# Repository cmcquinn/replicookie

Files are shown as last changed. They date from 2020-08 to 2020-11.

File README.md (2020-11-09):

# Replicookie





KiCad design files for Replicookie, a 3D Printer driver board based around the [Snickerdoodle](https://krtkl.com/snickerdoodle/) development board.

This project is open-source hardware, licensed under the CERN 1.2 license.

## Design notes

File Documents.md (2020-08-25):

# Supporting Documentation

## Snickerdoodle Development Board

<!-- <img src=https://krtkl.com/wp-content/uploads/2019/05/snickerdoodle-cj-down-1200x375.png> -->

| Document | Type |
| --- | --- |
| [Snickerdoodle Schematic](https://raw.githubusercontent.com/krtkl/open-source-schematics/master/snickerdoodle/snickerdoodle-schematic-r4p1.pdf) | Schematic |
| [Specifications](https://krtkl.com/resources/docs/#specs-snickerdoodle) | Specifications |
| [r4.1 Pinout](https://krtkl.com/uploads/pinout-r4.1.pdf) | Pinout |
| [Footprint](https://krtkl.com/uploads/footprint-snickerdoodle.pdf) | Footprint |

## Gigabit Ethernet PHY

<!-- <img src=https://www.microchip.com/_images/products/medium/041233a1fdc57dbe34369f35a1d2452f.png width=20%> -->

| Document                                                                                                                 |
| ------------------------------------------------------------------------------------------------------------------------ |
| [KSZ9031RNX Datasheet](http://ww1.microchip.com/downloads/en/DeviceDoc/00002117F.pdf)                                    |
| [Hardware Design Checklist](http://ww1.microchip.com/downloads/en/DeviceDoc/KSZ9031RNX-HW-Design-Checklist-00003391.pdf) |
| [Optimized Power Scheme](http://ww1.microchip.com/downloads/en/Appnotes/ANLAN206-UNG.pdf)                                |
| [Gigabit Ethernet Design Guide](http://ww1.microchip.com/downloads/en/Appnotes/00002054A.pdf)                            |

## MIC33050 Regulator

| Document                                                                                                                                                         |
| ---------------------------------------------------------------------------------------------------------------------------------------------------------------- |
| [MIC33050 Datasheet](http://ww1.microchip.com/downloads/en/DeviceDoc/MIC33050-4MHz-Internal-Inductor-PWM-Buck-Power-Module-with-HyperLight-Load-DS20006120A.pdf) |

## RJ45 Jack

<!-- <img src=https://media.digikey.com/Photos/Pulse%20Photos/JK0654219NL.jpg width=20%/> -->

| Document                                                                                        |
| ----------------------------------------------------------------------------------------------- |
| [JK Series Datasheet](https://media.digikey.com/pdf/Data%20Sheets/Pulse%20PDFs/JK%20Series.pdf) |

## USB ULPI Transceiver

| Document                                                                                                                            |
| ----------------------------------------------------------------------------------------------------------------------------------- |
| [USB334x Datasheet](http://ww1.microchip.com/downloads/en/DeviceDoc/USB334x-Data-Sheet-DS00002646A.pdf)                             |
| [USB Device Design Checklist](http://ww1.microchip.com/downloads/en/Appnotes/00001863B.pdf)                                         |
| [ULPI Design Guide](http://ww1.microchip.com/downloads/en/Appnotes/AN19.17-Application-Note-DS00002944A.pdf)                        |
| [USB334x USB Transceiver Layout Guidelines](http://ww1.microchip.com/downloads/en/Appnotes/AN22.3-Application-Note-DS00002971A.pdf) |
| [USB3343 Evaluation Board Schematic](http://ww1.microchip.com/downloads/en/DeviceDoc/SCH_USB3343-XTAL.pdf)                          |

## USB 2.0 Hi-Speed Hub Controller

| Document                                                                           |
| ---------------------------------------------------------------------------------- |
| [USB251x Datasheet](http://ww1.microchip.com/downloads/en/DeviceDoc/00001692C.pdf) |

## Dual High Speed USB to Multipurpose UART/FIFO

| Document                                                                                      |
| --------------------------------------------------------------------------------------------- |
| [FT4232H Datasheet](https://www.ftdichip.com/Support/Documents/DataSheets/ICs/DS_FT4232H.pdf) |

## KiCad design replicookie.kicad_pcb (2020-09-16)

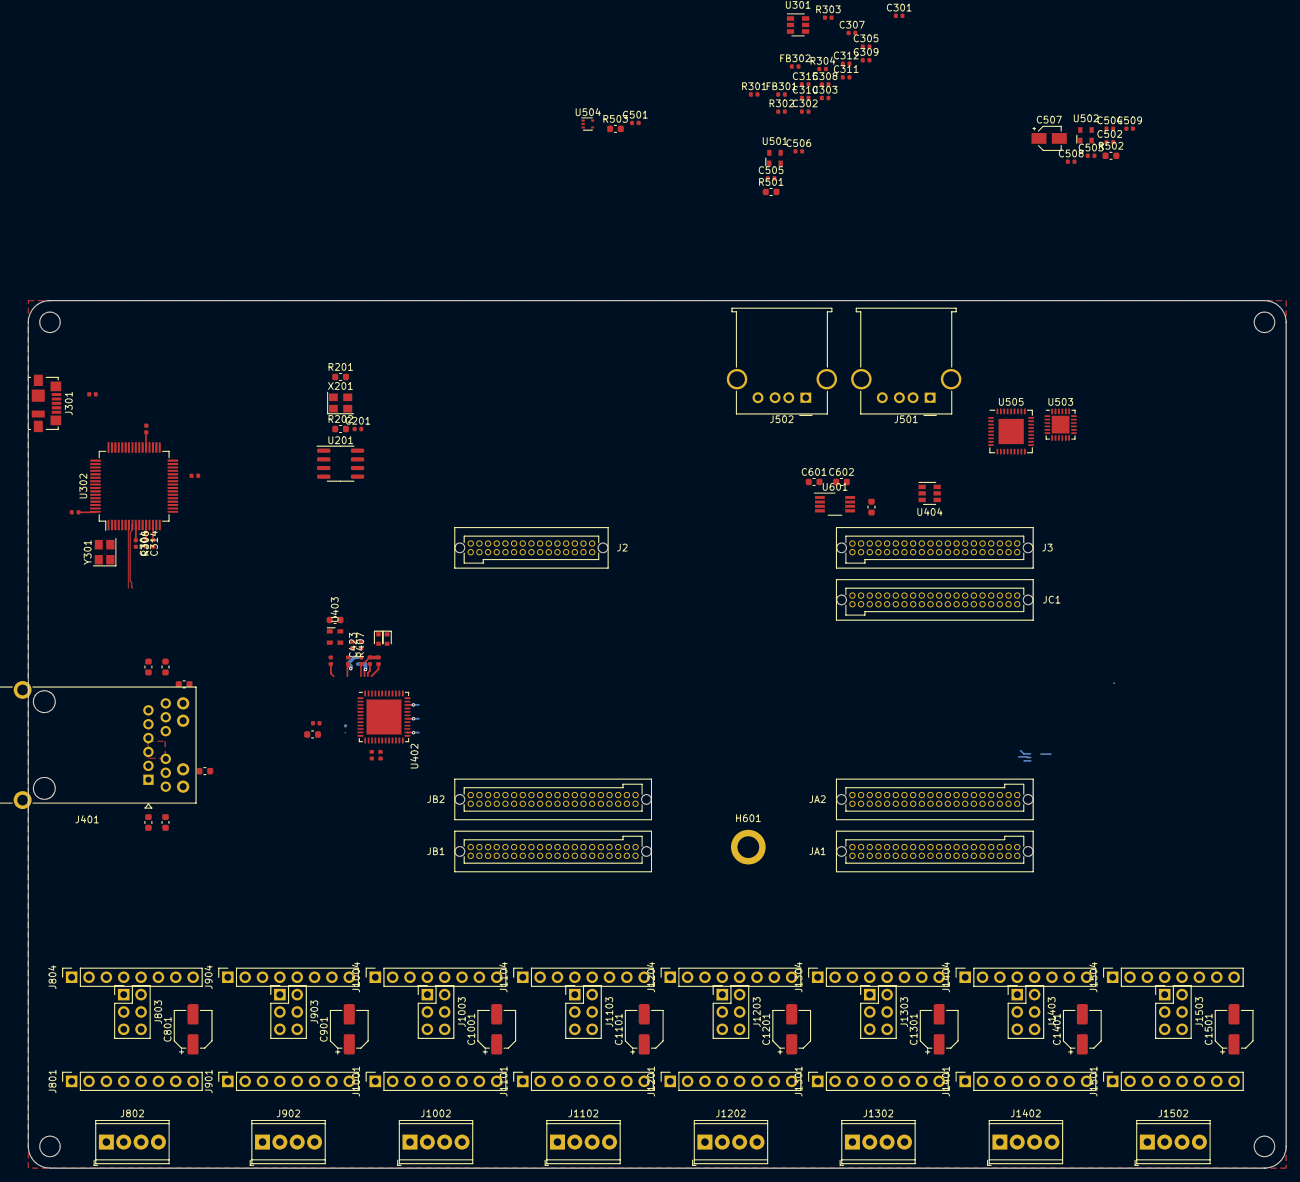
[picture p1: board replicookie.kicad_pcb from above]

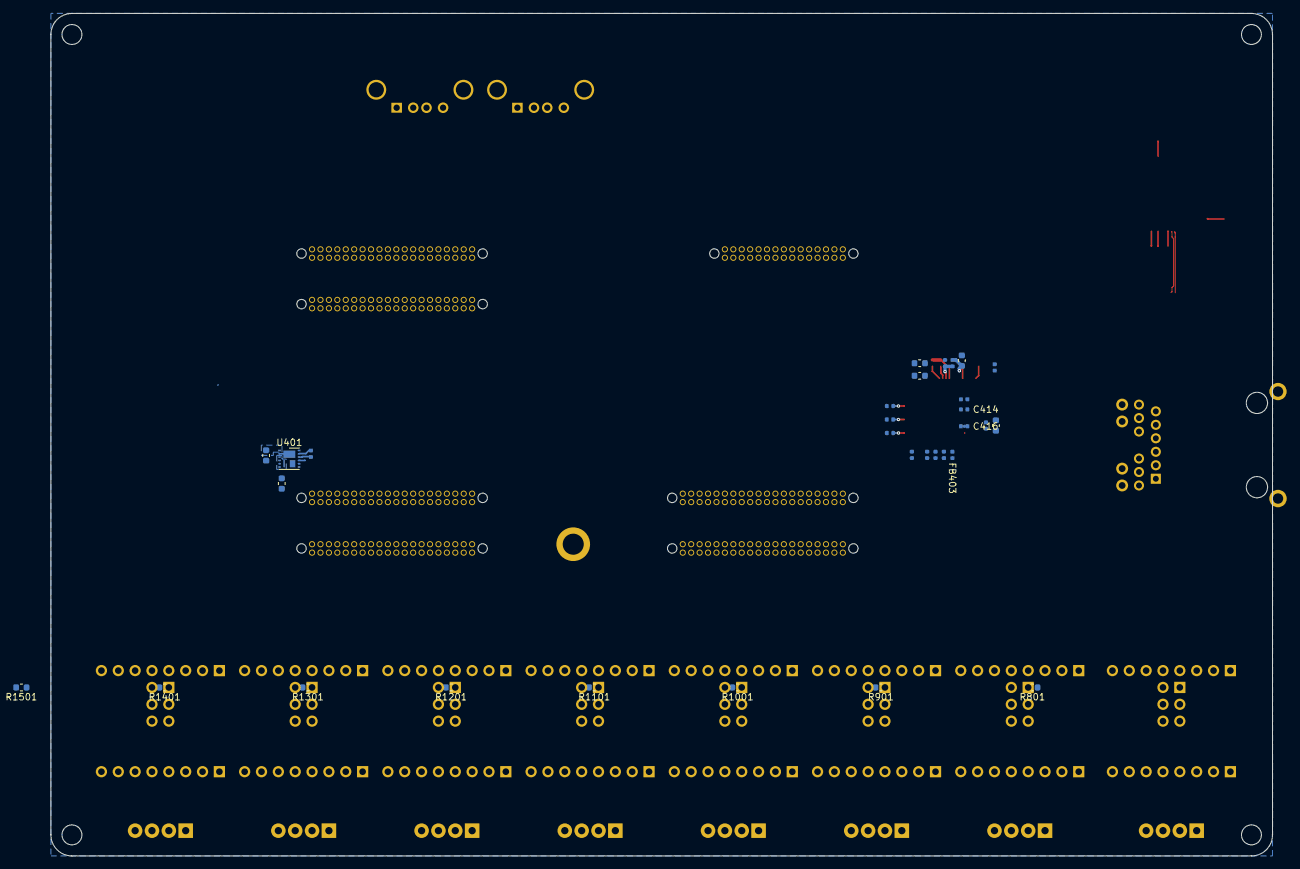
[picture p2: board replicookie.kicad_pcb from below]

Board: 4 copper layers, 184.1 x 127.0 mm, 163 parts (31 on the bottom side), 169 nets.

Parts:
C201, C501, C502: 0.01u; C_0402_1005Metric
C301, C303: 27p; C_0402_1005Metric
C302, C307, C308, C309, C310, C311, C312, C313, C314, C315, C408, C409, C410, C411, C412, C413, C414, C415, C416, C417, C418, C419, C420, C421, C504, C505, C508, C509: 0.1u; C_0402_1005Metric
C304, C305: 4.7u; C_0402_1005Metric
C306: 3.3u; C_0402_1005Metric
C401: 4.7u; C_0603_1608Metric
C402: 560p; C_0402_1005Metric
C403, C404, C405, C406, C407, C424: 10u; C_0603_1608Metric
C422: 0.01u; C_0603_1608Metric
C423: 10u; C_0402_1005Metric
C425, C426, C427, C428, C429, C601, C602: 0.1u; C_0603_1608Metric
C503, C506: 1u; C_0402_1005Metric
C507: 150u; CP_Elec_3x5.3
C801, C901, C1001, C1101, C1201, C1301, C1401, C1501: 100u 35V; CP_Elec_5x3
D401, D402: 1N4148WT; D_SOD-523
FB301, FB302: 80 ohm 100 MHz; L_0402_1005Metric
FB401, FB402, FB403: 100 ohms; L_0402_1005Metric
H101, H102, H103, H104: MountingHole; MountingHole_3mm
H601: MountingHole; Snickerdoodle_Mounting_Hole
J2: TFM-115-01-F-D-A; Samtec_TFM-115-01-F-D-A_2x15_P1.27mm_Horizontal
J3: TFM-120-01-F-D-A; Samtec_TFM-120-01-F-D-A_2x20_P1.27mm_Horizontal
J301: USB_B_Micro; USB_Micro-B_Molex_47346-0001
J401: JK0654219; RJ45_Pulse_JK0654219NL_Horizontal
J501, J502: USB_A; USB_A_Molex_67643_Horizontal
J801, J804, J901, J904, J1001, J1004, J1101, J1104, J1201, J1204, J1301, J1304, J1401, J1404, J1501, J1504: Conn_01x08_Female; PinSocket_1x08_P2.54mm_Vertical
J802, J902, J1002, J1102, J1202, J1302, J1402, J1502: Screw_Terminal_01x04; TerminalBlock_Phoenix_MPT-0,5-4-2.54_1x04_P2.54mm_Horizontal
J803, J903, J1003, J1103, J1203, J1303, J1403, J1503: Conn_02x03_Odd_Even; PinHeader_2x03_P2.54mm_Vertical
JA1, JA2: TFM-120-01-F-D-A; Samtec_TFM-120-01-F-D-A_2x20_P1.27mm_Horizontal
JB1, JB2: TFM-120-01-F-D-A; Samtec_TFM-120-01-F-D-A_2x20_P1.27mm_Horizontal
JC1: TFM-120-01-F-D-A; Samtec_TFM-120-01-F-D-A_2x20_P1.27mm_Horizontal
R201, R202: 2k; R_0603_1608Metric
R301, R302, R304, R401, R407: 10k; R_0402_1005Metric
R303: 2k; R_0402_1005Metric
R305: 12k; R_0402_1005Metric
R306, R403, R405: 1k; R_0402_1005Metric
R307: 470; R_0402_1005Metric
R402: 4.7k; R_0402_1005Metric
R404: 1.5k; R_0402_1005Metric
R406: 12.1k; R_0402_1005Metric
R408, R409: 75; R_0603_1608Metric
R501: 8.06k 1%; R_0603_1608Metric
R502: 10k 1/16W; R_0603_1608Metric
R503: 12k; R_0603_1608Metric
R801, R901, R1001, R1101, R1201, R1301, R1401, R1501: 10k; R_0603_1608Metric
U201: DS1307ZN+; SOIC-8_3.9x4.9mm_P1.27mm
U301: 93LCxxBxxOT; SOT-23-6
U302: FT4232H; LQFP-64_10x10mm_P0.5mm
U401: MIC33050-4YHL; HDFN-12-1EP_3x3mm_P0.5mm_EP1.8x1.125mm
U402: KSZ9031RNXCA; QFN-48-1EP_7x7mm_P0.5mm_EP5.15x5.15mm
U403: ASDMB-25.000MHz; Oscillator_SMD_Abracon_ASDMB-4Pin_2.5x2.0mm
U404: 74LVC2G07; SOT-23-6
U501: ASDMB-24.000MHz-C; Oscillator_SMD_Abracon_ASDMB-4Pin_2.5x2.0mm
U502: ASDMB-26.000MHz-C; Oscillator_SMD_Abracon_ASDMB-4Pin_2.5x2.0mm
U503: USB3343; QFN-24-1EP_4x4mm_P0.5mm_EP2.6x2.6mm
U504: 74LVC1G07; SOT-553
U505: USB2514B_Bi; QFN-36-1EP_6x6mm_P0.5mm_EP3.7x3.7mm
U601: TCA9800; VSSOP-8_3.0x3.0mm_P0.65mm
X201: ASE-xxxMHz; Oscillator_SMD_Abracon_ASE-4Pin_3.2x2.5mm
Y301: ABM8-12.000MHZ-20; Crystal_SMD_Abracon_ABM8G-4Pin_3.2x2.5mm

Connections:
+1V8: C501.1, C502.1, C601.2, U501.1 (Standby), U501.4 (VDD), U502.1 (Standby), U502.4 (VDD), U504.5 (VCC), U601.1 (VCCA)
+3V3: C201.1, C309.1, C310.1, C311.1, C312.1, C401.1, C405.1, C408.1, C409.1, C410.1, C422.1, C429.1, C602.2, D401.1 (K), FB301.2, FB302.2, FB403.1, J801.2, J803.1, J803.2, J901.2, J903.1, J903.2, J1001.2, J1003.1, J1003.2, J1101.2, J1103.1, J1103.2, J1201.2, J1203.1, J1203.2, J1301.2, J1303.1, J1303.2, J1401.2, J1403.1, J1403.2, J1501.2, J1503.1, J1503.2, R201.1, R202.1, R301.1, R302.1, R304.1, R306.1, R401.1, R402.1, R404.1, R407.1, R408.2, R409.2, R801.1, R901.1, R1001.1, R1101.1, R1201.1, R1301.1, R1401.1, R1501.1, U201.8 (VCC), U302.20 (VCCIO), U302.31 (VCCIO), U302.42 (VCCIO), U302.50 (VREGIN), U302.56 (VCCIO), U401.1 (VIN), U401.9 (EN), U402.16 (DVDDH), U402.34 (DVDDH), U402.40 (DVDDH), U403.1 (Standby), U403.4 (VDD), U404.5 (VCC), U505.27 (VBUS_DET), U601.8 (VCCB), X201.1 (EN), X201.4 (Vdd)
+24V: C801.1, C901.1, C1001.1, C1101.1, C1201.1, C1301.1, C1401.1, C1501.1, J801.8, J901.8, J1001.8, J1101.8, J1201.8, J1301.8, J1401.8, J1501.8
/DRV0_CTRL.~EN: J804.8, R801.2
/DRV1_CTRL.~EN: J904.8, R901.2
/DRV2_CTRL.~EN: J1004.8, R1001.2
/DRV3_CTRL.~EN: J1104.8, R1101.2
/DRV4_CTRL.~EN: J1204.8, R1201.2
/DRV5_CTRL.~EN: J1304.8, R1301.2
/DRV6_CTRL.~EN: J1404.8, R1401.2
/DRV7_CTRL.~EN: J1504.8, R1501.2
/ETHERNET.MDC: JB2.37, U402.36 (MDC)
/ETHERNET.MDIO: JB2.35, R404.2, U402.37 (MDIO)
/ETHERNET.RXD0: JB2.30, U402.32 (RXD0/MODE0)
/ETHERNET.RXD1: JB2.26, U402.31 (RXD1/MODE1)
/ETHERNET.RXD2: JB2.24, U402.28 (RXD2/MODE2)
/ETHERNET.RXD3: JB2.20, U402.27 (RXD3/MODE3)
/ETHERNET.RX_CLK: JB2.36, U402.35 (RX_CLK/PHYAD2)
/ETHERNET.RX_CTL: JB2.32, U402.33 (RX_DV/CLK125_EN)
/ETHERNET.TXD0: JB2.4, U402.19 (TXD0)
/ETHERNET.TXD1: JB2.6, U402.20 (TXD1)
/ETHERNET.TXD2: JB2.8, U402.21 (TXD2)
/ETHERNET.TXD3: JB2.12, U402.22 (TXD3)
/ETHERNET.TX_CLK: JB2.14, U402.24 (GTX_CLK)
/ETHERNET.TX_CTL: JB2.18, U402.25 (TX_EN)
/Ethernet/25MHZ_CLK: U402.46 (XI), U403.3 (Out)
/Ethernet/AVDDH: C411.1, C412.1, C424.1, FB403.2, U402.1 (AVDDH), U402.12 (AVDDH)
/Ethernet/AVDDL: C406.1, C414.1, C416.1, FB401.1, U402.4 (AVDDL), U402.9 (AVDDL)
/Ethernet/AVDDL_PLL: C407.1, C417.1, FB402.1, U402.44 (AVDDL_PLL)
/Ethernet/CFF: C402.2, U401.11 (CFF)
/Ethernet/CT1: C428.1, J401.12 (MXCT1)
/Ethernet/CT2: C427.1, J401.6 (MXCT2)
/Ethernet/CT3: C426.1, J401.1 (MXCT3)
/Ethernet/CT4: C425.1, J401.7 (MXCT4)
/Ethernet/DVDDL: C402.1, C403.1, C404.1, C413.1, C415.1, C418.1, C419.1, C420.1, C421.1, FB401.2, FB402.2, U401.7 (VOUT), U401.8 (VOUT), U401.10 (SNS), U402.14 (DVDDL), U402.18 (DVDDL), U402.23 (DVDDL), U402.26 (DVDDL), U402.30 (DVDDL), U402.39 (DVDDL)
/Ethernet/ISET: R406.1, U402.48 (ISET)
/Ethernet/LED1: R403.1, U402.17 (LED1/PHAD0/PME_N1), U404.1
/Ethernet/LED1A: J401.16 (LED1+), R409.1
/Ethernet/LED1K: J401.15 (LED1-), U404.6
/Ethernet/LED2: R405.1, U402.15 (LED2/PHYAD1), U404.3
/Ethernet/LED2A: J401.14 (LED2+), R408.1
/Ethernet/LED2K: J401.13 (LED2-), U404.4
/Ethernet/LED_MODE: R401.2, U402.41 (CLK125_NDO/LED_MODE)
/Ethernet/TXRXA+: J401.11 (MX1+), U402.2 (TXRXP_A)
/Ethernet/TXRXA-: J401.10 (MX1-), U402.3 (TXRXM_A)
/Ethernet/TXRXB+: J401.4 (MX2+), U402.5 (TXRXP_B)
/Ethernet/TXRXB-: J401.5 (MX2-), U402.6 (TXRXM_B)
/Ethernet/TXRXC+: J401.3 (MX3+), U402.7 (TXRXP_C)
/Ethernet/TXRXC-: J401.2 (MX3-), U402.8 (TXRXM_C)
/Ethernet/TXRXD+: J401.8 (MX4+), U402.10 (TXRXP_D)
/Ethernet/TXRXD-: J401.9 (MX4-), U402.11 (TXRXM_D)
/Ethernet/~ENET_RST: C423.1, D401.2 (A), D402.2 (A), R407.2, U402.42 (RESET_N)
/Ethernet/~INT~/~PME2: R402.2, U402.38 (INT_N/PME_N2)
/FTDI/D+: J301.3 (D+), U302.8 (DP)
/FTDI/D-: J301.2 (D-), U302.7 (DM)
/FTDI/EECLK: R301.2, U301.4 (CLK), U302.62 (EECLK)
/FTDI/EECS: R304.2, U301.5 (CS), U302.63 (EECS)
/FTDI/EEDATA: R303.1, U301.3 (DI), U302.61 (EEDATA)
/FTDI/EEDO: R302.2, R303.2, U301.1 (DO)
/FTDI/FTDI_1V8: C306.1, C313.1, C314.1, C315.1, U302.12 (VCORE), U302.37 (VCORE), U302.49 (VREGOUT), U302.64 (VCORE)
/FTDI/OSCI: C301.2, U302.2 (OSCI), Y301.3
/FTDI/OSCO: C303.1, U302.3 (OSCO), Y301.1
/FTDI/REF: R305.1, U302.6 (REF)
/FTDI/VPHY: C305.1, C308.1, FB302.1, U302.4 (VPHY)
/FTDI/VPLL: C304.1, C307.1, FB301.1, U302.9 (VPLL)
/FTDI/~FTDI_RESET: R306.2, U302.14 (~RESET)
/MCU_~RST: J2.17, U302.29 (BDBUS3)
/MotorDrivers/Driver0/ADDR0: J803.4, J804.7
/MotorDrivers/Driver0/ADDR1: J803.3, J804.6
/MotorDrivers/Driver0/M1A: J801.4, J802.2
/MotorDrivers/Driver0/M1B: J801.3, J802.1
/MotorDrivers/Driver0/M2A: J801.5, J802.3
/MotorDrivers/Driver0/M2B: J801.6, J802.4
/MotorDrivers/Driver1/ADDR0: J903.4, J904.7
/MotorDrivers/Driver1/ADDR1: J903.3, J904.6
/MotorDrivers/Driver1/M1A: J901.4, J902.2
/MotorDrivers/Driver1/M1B: J901.3, J902.1
/MotorDrivers/Driver1/M2A: J901.5, J902.3
/MotorDrivers/Driver1/M2B: J901.6, J902.4
/MotorDrivers/Driver2/ADDR0: J1003.4, J1004.7
/MotorDrivers/Driver2/ADDR1: J1003.3, J1004.6
/MotorDrivers/Driver2/M1A: J1001.4, J1002.2
/MotorDrivers/Driver2/M1B: J1001.3, J1002.1
/MotorDrivers/Driver2/M2A: J1001.5, J1002.3
/MotorDrivers/Driver2/M2B: J1001.6, J1002.4
/MotorDrivers/Driver3/ADDR0: J1103.4, J1104.7
/MotorDrivers/Driver3/ADDR1: J1103.3, J1104.6
/MotorDrivers/Driver3/M1A: J1101.4, J1102.2
/MotorDrivers/Driver3/M1B: J1101.3, J1102.1
/MotorDrivers/Driver3/M2A: J1101.5, J1102.3
/MotorDrivers/Driver3/M2B: J1101.6, J1102.4
/MotorDrivers/Driver4/ADDR0: J1203.4, J1204.7
/MotorDrivers/Driver4/ADDR1: J1203.3, J1204.6
/MotorDrivers/Driver4/M1A: J1201.4, J1202.2
/MotorDrivers/Driver4/M1B: J1201.3, J1202.1
/MotorDrivers/Driver4/M2A: J1201.5, J1202.3
/MotorDrivers/Driver4/M2B: J1201.6, J1202.4
/MotorDrivers/Driver5/ADDR0: J1303.4, J1304.7
/MotorDrivers/Driver5/ADDR1: J1303.3, J1304.6
/MotorDrivers/Driver5/M1A: J1301.4, J1302.2
/MotorDrivers/Driver5/M1B: J1301.3, J1302.1
/MotorDrivers/Driver5/M2A: J1301.5, J1302.3
/MotorDrivers/Driver5/M2B: J1301.6, J1302.4
/MotorDrivers/Driver6/ADDR0: J1403.4, J1404.7
/MotorDrivers/Driver6/ADDR1: J1403.3, J1404.6
/MotorDrivers/Driver6/M1A: J1401.4, J1402.2
/MotorDrivers/Driver6/M1B: J1401.3, J1402.1
/MotorDrivers/Driver6/M2A: J1401.5, J1402.3
/MotorDrivers/Driver6/M2B: J1401.6, J1402.4
/MotorDrivers/Driver7/ADDR0: J1503.4, J1504.7
/MotorDrivers/Driver7/ADDR1: J1503.3, J1504.6
/MotorDrivers/Driver7/M1A: J1501.4, J1502.2
/MotorDrivers/Driver7/M1B: J1501.3, J1502.1
/MotorDrivers/Driver7/M2A: J1501.5, J1502.3
/MotorDrivers/Driver7/M2B: J1501.6, J1502.4
/RealTimeClock/REF_CLK: U201.1 (X1), X201.3 (OUT)
/SMB_I2C0.SCL: JA1.39, R201.2, U201.6 (SCL)
/SMB_I2C0.SDA: JA1.40, R202.2, U201.5 (SDA)
/SWCLK: J2.15, U302.26 (BDBUS0)
/SWDIO: J2.16, R307.2, U302.28 (BDBUS2)
/Snickerdoodle/SCL: J3.8, U601.2 (SCLA)
/TCK: J2.21, U302.16 (ADBUS0)
/TDI: J2.22, U302.17 (ADBUS1)
/TDO: J2.24, U302.18 (ADBUS2)
/TMS: J2.23, U302.19 (ADBUS3)
/UART0: J804.4, J904.4, J1004.4, J1104.4
/UART1: J1204.4, J1304.4, J1404.4, J1504.4
/USB.CLK: J3.35, U503.2 (CLKOUT)
/USB.DATA0: J3.29, U503.4 (DATA0)
/USB.DATA1: J3.31, U503.5 (DATA1)
/USB.DATA2: J3.32, U503.6 (DATA2)
/USB.DATA3: J3.30, U503.7 (DATA3)
/USB.DATA4: J3.23, U503.8 (DATA4)
/USB.DATA5: J3.37, U503.10 (DATA5)
/USB.DATA6: J3.38, U503.11 (DATA6)
/USB.DATA7: J3.36, U503.12 (DATA7)
/USB.DIR: J3.25, U503.1 (DIR)
/USB.NXT: J3.24, U503.3 (NXT)
/USB.STP: J3.26, U503.24 (STP)
/USB/D1N: J501.2 (D-), U505.2 (USBDP_DN1/PRT_DIS_P1)
/USB/D1P: J501.3 (D+), U505.1 (USBDM_DN1/PRT_DIS_M1)
/USB/D2N: J502.2 (D-), U505.4 (USBDP_DN2/PRT_DIS_P2)
/USB/D2P: J502.3 (D+), U505.3 (USBDM_DN2/PRT_DIS_M2)
/USB/DM: U503.14 (DM), U505.30 (USBDM_UP)
/USB/DP: U503.13 (DP), U505.31 (USBDP_UP)
/USB/REFCLK: U502.3 (Out), U503.21 (REFCLK/XI)
/USB/VBUS: R502.1, U503.17 (VBUS)
/USB/VBUS_OUT: C507.1, R502.2
/USB/VDD33: C506.1, U503.15 (VDD33), U503.18 (ID)
/USB/~HUB_RESET: U504.4, U505.26 (RESET_N)
/ZYNQ_~RST: J2.19, U302.21 (ADBUS4)
/~ETHERNET_RST: D402.1 (K), JB2.38
/~USB_RST: U503.22 (~RESETB), U504.2
BANKA_VIO: JA1.3, JA2.3
BANKB_VIO: JB1.3, JB2.3
BANKC_VIO: J3.3, JC1.3
GND: C201.2, C301.1, C302.2, C303.2, C304.2, C305.2, C306.2, C307.2, C308.2, C309.2, C310.2, C311.2, C312.2, C313.2, C314.2, C315.2, C401.2, C403.2, C404.2, C405.2, C406.2, C407.2, C408.2, C409.2, C410.2, C411.2, C412.2, C413.2, C414.2, C415.2, C416.2, C417.2, C418.2, C419.2, C420.2, C421.2, C422.2, C423.2, C424.2, C425.2, C426.2, C427.2, C428.2, C429.2, C503.2, C504.2, C505.2, C506.2, C507.2, C508.2, C509.2, C601.1, C602.1, C801.2, C901.2, C1001.2, C1101.2, C1201.2, C1301.2, C1401.2, C1501.2, J2.5, J2.6, J2.9, J2.10, J2.20, J2.27, J2.28, J3.9, J3.10, J3.15, J3.16, J3.21, J3.22, J3.27, J3.28, J3.33, J3.34, J301.5 (GND), J301.6 (Shield), J401.SH, J803.5, J803.6, J903.5, J903.6, J1003.5, J1003.6, J1103.5, J1103.6, J1203.5, J1203.6, J1303.5, J1303.6, J1403.5, J1403.6, J1503.5, J1503.6, JA1.9, JA1.10, JA1.15, JA1.16, JA1.21, JA1.22, JA1.27, JA1.28, JA1.33, JA1.34, JA2.9, JA2.10, JA2.15, JA2.16, JA2.21, JA2.22, JA2.27, JA2.28, JA2.33, JA2.34, JB1.9, JB1.10, JB1.15, JB1.16, JB1.21, JB1.22, JB1.27, JB1.28, JB1.33, JB1.34, JB2.9, JB2.10, JB2.15, JB2.16, JB2.21, JB2.22, JB2.27, JB2.28, JB2.33, JB2.34, JC1.9, JC1.10, JC1.15, JC1.16, JC1.21, JC1.22, JC1.27, JC1.28, JC1.33, JC1.34, R305.2, R403.2, R405.2, R406.2, R501.2, R503.2, U201.4 (GND), U301.2 (GND), U302.1 (GND), U302.5 (GND), U302.10 (AGND), U302.11 (GND), U302.13 (TEST), U302.15 (GND), U302.25 (GND), U302.35 (GND), U302.47 (GND), U302.51 (GND), U401.2 (PGND), U401.12 (AGND), U401.13 (EP), U402.29 (VSS), U402.49 (PAD_GND), U403.2 (GND), U404.2 (GND), U503.25 (GND), U504.3 (GND), U505.37 (VSS), U601.4 (GND), X201.2 (GND), Y301.2, Y301.4
unnamed: C302.1, U301.6 (VCC)
unnamed: C501.2, U501.2 (GND)
unnamed: C502.2, U502.2 (GND)
unnamed: C503.1, C504.1, U503.9 (VDDIO), U503.23 (VDD18)
unnamed: C505.1, U503.16 (VBAT)
unnamed: C508.1, U505.34 (PLLFILT)
unnamed: C509.1, U505.14 (CRFILT)
unnamed: R307.1, U302.27 (BDBUS1)
unnamed: R501.1, U503.19 (RBIAS)
unnamed: R503.1, U505.35 (RBIAS)
unnamed: U401.3 (SW), U401.4 (SW), U401.5 (SW), U401.6 (SW)
ZYNQ_VIN: J2.29, J2.30

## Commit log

2020-06-25 Initial commit with template and motor drivers
    [MotorDrivers.kicad_sch, StepStick.kicad_sch, motor_drivers.kicad_sch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]
2020-06-25 Increase text size, redo bus labels
    [MotorDrivers.kicad_sch, StepStick.kicad_sch, replicookie.kicad_sch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]
2020-06-25 Configure driver chip address with jumpers
    [MotorDrivers.kicad_sch, StepStick.kicad_sch, replicookie.kicad_sch]
2020-06-25 Add RTC
    [MotorDrivers.kicad_sch, RTC.kicad_sch, StepStick.kicad_sch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]
2020-07-06 Working on gigabit ethernet PHY
    [MotorDrivers.kicad_sch, RTC.kicad_sch, StepStick.kicad_sch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]
2020-07-08 WIre Ethernet PHY
    [ethernet.kicad_sch, replicookie.kicad_sch, snickerdoodle.kicad_sch]
2020-07-08 Finish ethernet sheet, update power calculations
    [ethernet.kicad_sch]
2020-07-08 Annotate schematic
    [MotorDrivers.kicad_sch, RTC.kicad_sch, StepStick.kicad_sch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]
2020-07-10 Add ULPI USB PHY
    [MotorDrivers.kicad_sch, RTC.kicad_sch, StepStick.kicad_sch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]
2020-07-11 Fix footprint associations, use 74LVC2G07 instead of MOSFETs
    [RTC.kicad_sch, StepStick.kicad_sch, USB.kicad_sch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]
2020-07-12 Connect Ethernet and USB to MIO, start layout
    [RTC.kicad_sch, StepStick.kicad_sch, USB.kicad_sch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]
2020-07-14 Place motor drivers, start layout of Ethernet PHY
    [MotorDrivers.kicad_sch, RTC.kicad_sch, StepStick.kicad_sch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]
2020-07-15 Add FTDI chip
    [FTDI.kicad_sch, MotorDrivers.kicad_sch, RTC.kicad_sch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]
2020-07-26 Connect Ethernet PHY to FPGA, route RGMII signals
    [FTDI.kicad_sch, MotorDrivers.kicad_sch, RTC.kicad_sch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]
2020-08-05 Attach ethernet to PL, layout and route
    [FTDI.kicad_sch, MotorDrivers.kicad_sch, RTC.kicad_sch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]
2020-08-08 Move Ethernet around to save space
    [FTDI.kicad_sch, MotorDrivers.kicad_sch, RTC.kicad_sch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]
2020-08-25 Expand PCB, change to inches, center Snickerdoodle
    [FTDI.kicad_sch, MotorDrivers.kicad_sch, RTC.kicad_sch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]
2020-09-16 Move Ethernet PHY to left side of board
    [FTDI.kicad_sch, MotorDrivers.kicad_sch, RTC.kicad_sch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]
2020-10-18 Route RGMII signals
    [FTDI.kicad_sch, USB.kicad_sch, ethernet.kicad_sch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]
2020-10-29 Layout Ethernet PHY decoupling capacitors
    [FTDI.kicad_sch, MotorDrivers.kicad_sch, RTC.kicad_sch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]
2020-10-29 Setup git filters h/t https://jnavila.github.io/plotkicadsch/
    [StepStick.kicad_sch, USB.kicad_sch, ethernet.kicad_sch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]
2020-10-30 Add filled zones for Ethernet power
2020-10-31 Switch to stacked USB ports
    [FTDI.kicad_sch, RTC.kicad_sch, StepStick.kicad_sch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]
2020-10-31 Ethernet: Route missing track
2020-10-31 Layout Ethernet core power regulator
    [ethernet.kicad_sch, replicookie.kicad_sch, snickerdoodle.kicad_sch]
2020-11-06 Layout Ethernet clock and pull-up resistors
    [USB.kicad_sch, ethernet.kicad_sch, replicookie.kicad_sch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]
2020-11-08 Route ULPI signals
    [StepStick.kicad_sch, USB.kicad_sch, ethernet.kicad_sch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]
2020-11-09 Connect USB clock generators to gnd, add clock termination resistor
    [USB.kicad_sch]
2020-11-11 Power USB REFCLK from PHY regulator, add pull up resistors to USB reset line
    [USB.kicad_sch]
2020-11-25 WIP: layout USB host interface
    [USB.kicad_sch, ethernet.kicad_sch, replicookie.kicad_sch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]
2021-01-06 Switch to 6 layer stackup, route ULPI
